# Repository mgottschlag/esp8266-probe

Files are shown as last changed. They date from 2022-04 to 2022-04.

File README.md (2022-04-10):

# esp8266-probe

This repository contains a PCB design for a WIFI JTAG probe using the ESP-12
ESP8266 module. The probe is designed to be compatible with
[blackmagic-espidf](https://github.com/walmis/blackmagic-espidf). The JTAG
signals (+UART) are connected as follows to ESP8266 GPIOs:

| JTAG Signal | GPIO |
| --- | ---- |
| TXD | 1 |
| RXD | 3 |
| TMS/SWDIO | 4 |
| TCK/SWCLK | 5 |
| SRST | 12 |
| TDI | 13 |
| TDO | 14 |

In addition, the 10-pin connector provides 5V and 3.3V supplies. The PCB is
provided with power via USB and 3.3V is provided by a cheap 1117 linear
regulator.

## License

The design is licensed under the [CERN Open Hardware Licence Version 2 - Permissive](cern-ohl_p_v2.txt).

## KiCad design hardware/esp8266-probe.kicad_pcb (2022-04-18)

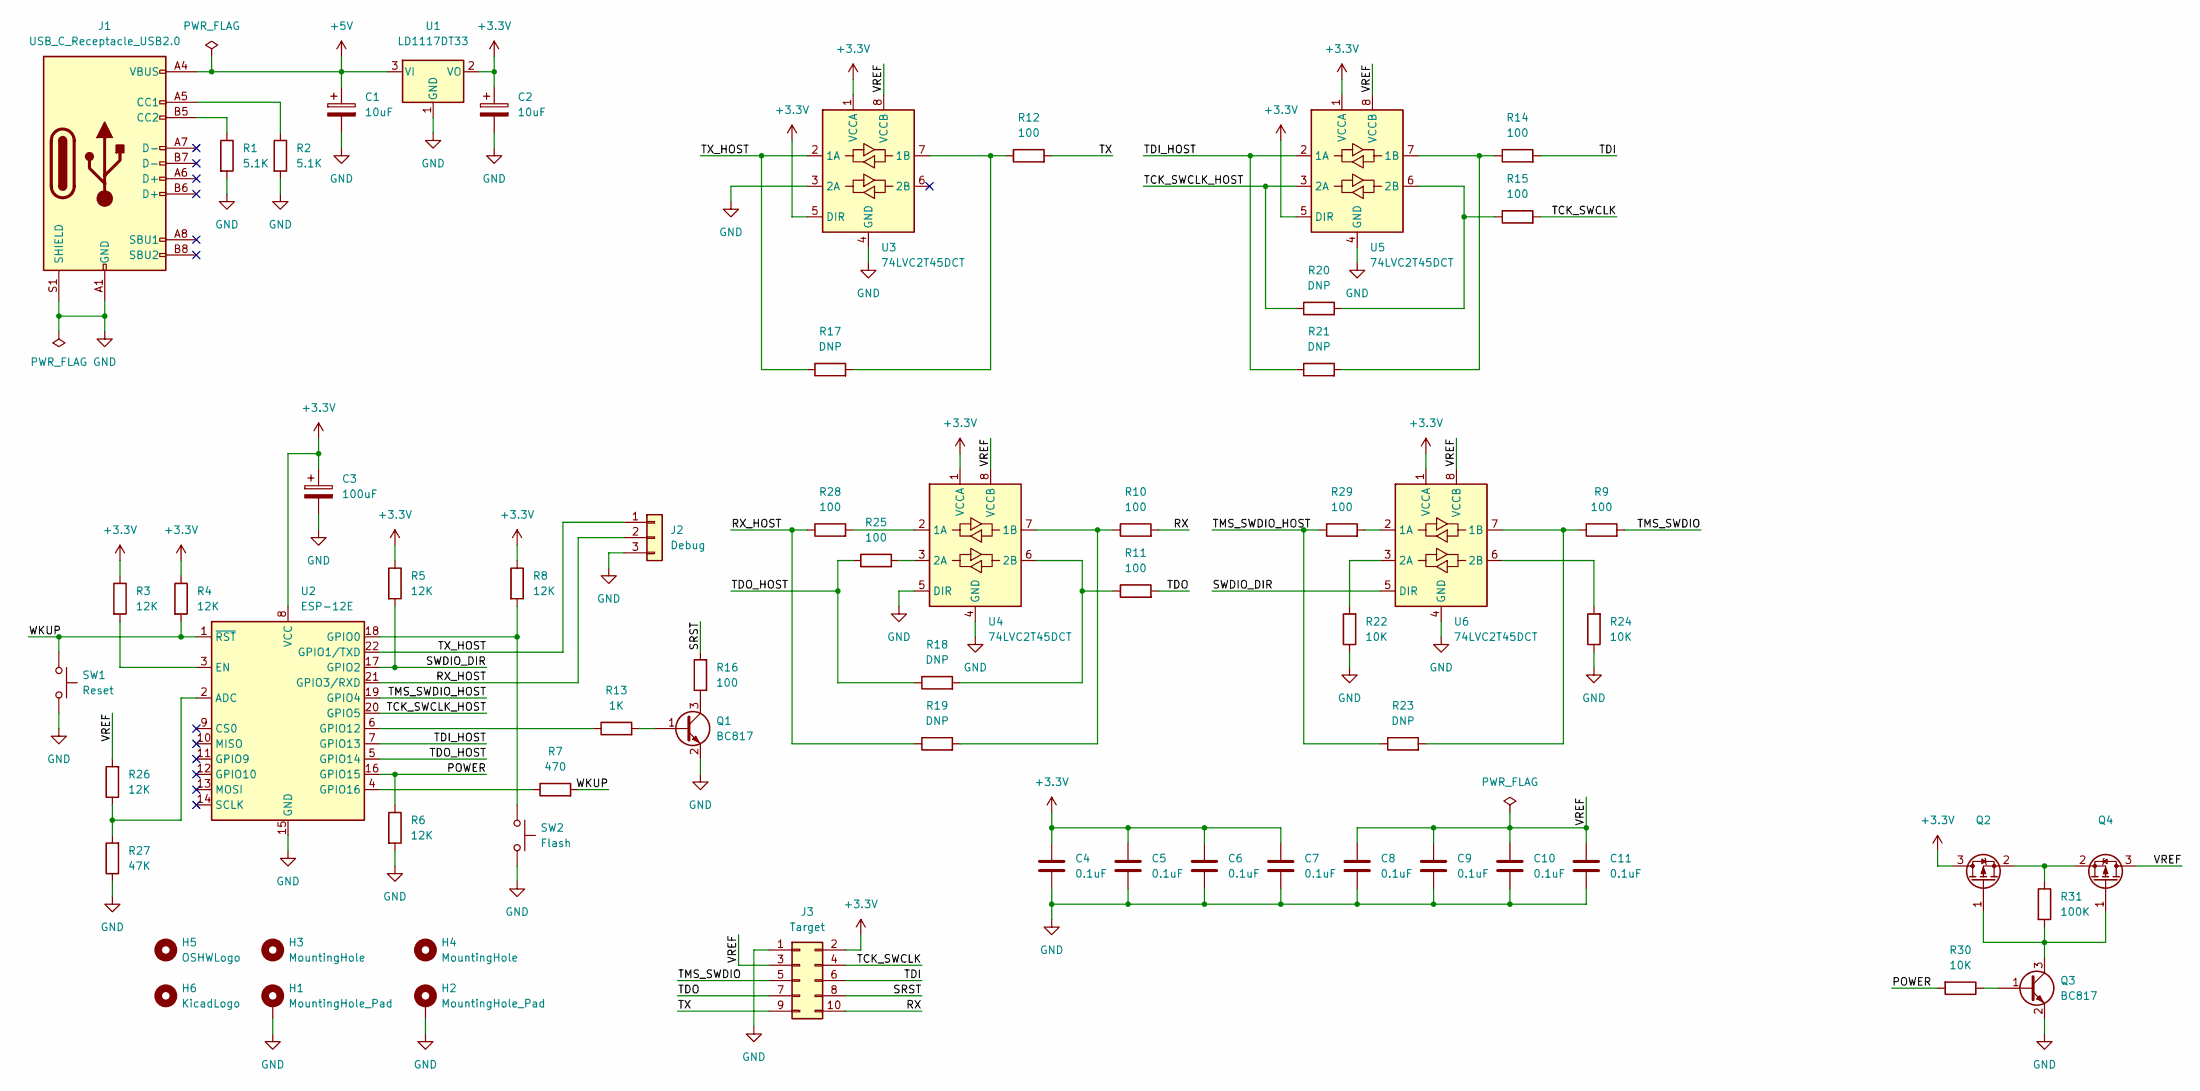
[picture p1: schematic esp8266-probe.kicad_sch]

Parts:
C1, C2: 10uF; CP_EIA-6032-20_AVX-F_Pad2.25x2.35mm_HandSolder
C3: 100uF; CP_Radial_D6.3mm_P2.50mm
C4, C5, C6, C7, C8, C9, C10, C11: 0.1uF; C_0603_1608Metric
H1, H2: MountingHole_Pad; MountingHole_3.2mm_M3_Pad
H3, H4: MountingHole; MountingHole_3.2mm_M3
H5: OSHWLogo; OSHW-Logo_5.7x6mm_SilkScreen
H6: KicadLogo; KiCad-Logo2_5mm_SilkScreen
J1: USB_C_Receptacle_USB2.0; USB_C_Receptacle_HRO_TYPE-C-31-M-12
J2: Debug; PinHeader_1x03_P2.54mm_Vertical
J3: Target; IDC-Header_2x05_P2.54mm_Vertical
Q1, Q3: BC817; SOT-23
Q2: (no value)
Q4: SOT-23
R1, R2: 5.1K; R_0603_1608Metric
R3, R4, R5, R6, R8, R26: 12K; R_0603_1608Metric
R7: 470; R_0603_1608Metric
R9, R10, R11, R12, R14, R15, R16, R25, R28, R29: 100; R_0603_1608Metric
R13: 1K; R_0603_1608Metric
R17, R18, R19, R20, R21, R23: DNP; R_0603_1608Metric
R22, R24, R30: 10K; R_0603_1608Metric
R27: 47K; R_0603_1608Metric
R31: 100K; R_0603_1608Metric
SW1: Reset; SW_SPST_PTS810
SW2: Flash; SW_SPST_PTS810
U1: LD1117DT33; TO-252-2
U2: ESP-12E
U3, U4, U5, U6: 74LVC2T45DCT; VSSOP-8_3.0x3.0mm_P0.65mm

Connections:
+3V3: C2.1, C3.1, C4.1, C5.1, C6.1, C7.1, J3.2, Q2.3 (D), R3.1, R4.1, R5.1, R8.1, U1.2 (VO), U2.8 (VCC), U3.1 (VCCA), U3.5 (DIR), U4.1 (VCCA), U5.1 (VCCA), U5.5 (DIR), U6.1 (VCCA)
+5V: C1.1, J1.A4 (VBUS), J1.A9 (VBUS), J1.B4 (VBUS), J1.B9 (VBUS), U1.3 (VI)
/POWER: R6.1, R30.2, U2.16 (GPIO15)
/RX: J3.10, R10.2
/RX_HOST: J2.2, R19.1, R28.1, U2.21 (GPIO3/RXD)
/SRST: J3.8, R16.2
/SWDIO_DIR: R5.2, U2.17 (GPIO2), U6.5 (DIR)
/TCK_SWCLK: J3.4, R15.2
/TCK_SWCLK_HOST: R20.1, U2.20 (GPIO5), U5.3 (2A)
/TDI: J3.6, R14.2
/TDI_HOST: R21.1, U2.7 (GPIO13), U5.2 (1A)
/TDO: J3.7, R11.2
/TDO_HOST: R18.1, R25.1, U2.5 (GPIO14)
/TMS_SWDIO: J3.5, R9.2
/TMS_SWDIO_HOST: R23.1, R29.1, U2.19 (GPIO4)
/TX: J3.9, R12.2
/TX_HOST: J2.1, R17.1, U2.22 (GPIO1/TXD), U3.2 (1A)
/VREF: C8.1, C9.1, C10.1, C11.1, J3.3, Q4.3 (D), R26.2, U3.8 (VCCB), U4.8 (VCCB), U5.8 (VCCB), U6.8 (VCCB)
/WKUP: R4.2, R7.2, SW1.1, U2.1 (~RST)
GND: C1.2, C2.2, C3.2, C4.2, C5.2, C6.2, C7.2, C8.2, C9.2, C10.2, C11.2, H1.1, H2.1, J1.A1 (GND), J1.A12 (GND), J1.B1 (GND), J1.B12 (GND), J1.S1 (SHIELD), J2.3, J3.1, Q1.2 (E), Q3.2 (E), R1.2, R2.2, R6.2, R22.1, R24.1, R27.1, SW1.2, SW2.2, U1.1 (GND), U2.15 (GND), U3.3 (2A), U3.4 (GND), U4.4 (GND), U4.5 (DIR), U5.4 (GND), U6.4 (GND)
unnamed: J1.A5 (CC1), R2.1
unnamed: J1.B5 (CC2), R1.1
unnamed: Q1.1 (B), R13.2
unnamed: Q1.3 (C), R16.1
unnamed: Q2.1 (G), Q3.3 (C), Q4.1 (G), R31.2
unnamed: Q2.2 (S), Q4.2 (S), R31.1
unnamed: Q3.1 (B), R30.1
unnamed: R3.2, U2.3 (EN)
unnamed: R7.1, U2.4 (GPIO16)
unnamed: R8.2, SW2.1, U2.18 (GPIO0)
unnamed: R10.1, R19.2, U4.7 (1B)
unnamed: R11.1, R18.2, U4.6 (2B)
unnamed: R12.1, R17.2, U3.7 (1B)
unnamed: R13.1, U2.6 (GPIO12)
unnamed: R14.1, R21.2, U5.7 (1B)
unnamed: R15.1, R20.2, U5.6 (2B)
unnamed: R22.2, U6.3 (2A)
unnamed: R9.1, R23.2, U6.7 (1B)
unnamed: R24.2, U6.6 (2B)
unnamed: R25.2, U4.3 (2A)
unnamed: R26.1, R27.2, U2.2 (ADC)
unnamed: R28.2, U4.2 (1A)
unnamed: R29.2, U6.2 (1A)

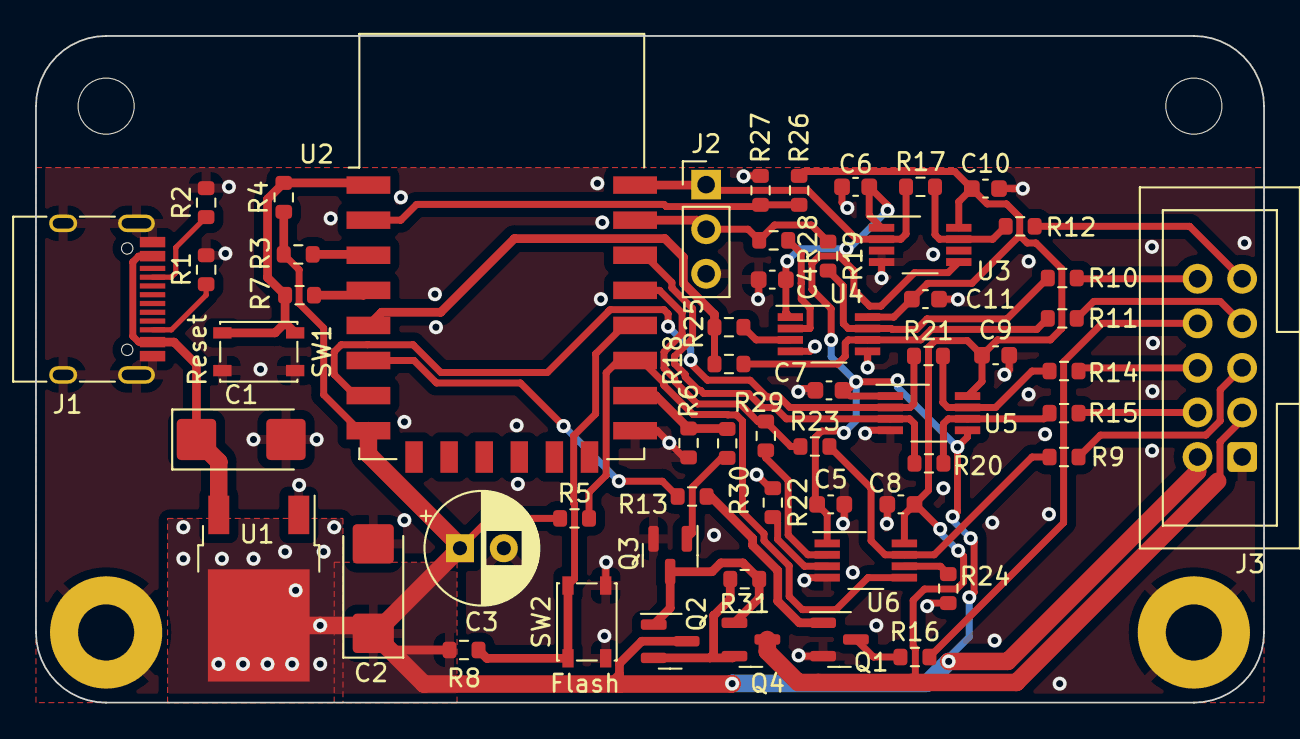
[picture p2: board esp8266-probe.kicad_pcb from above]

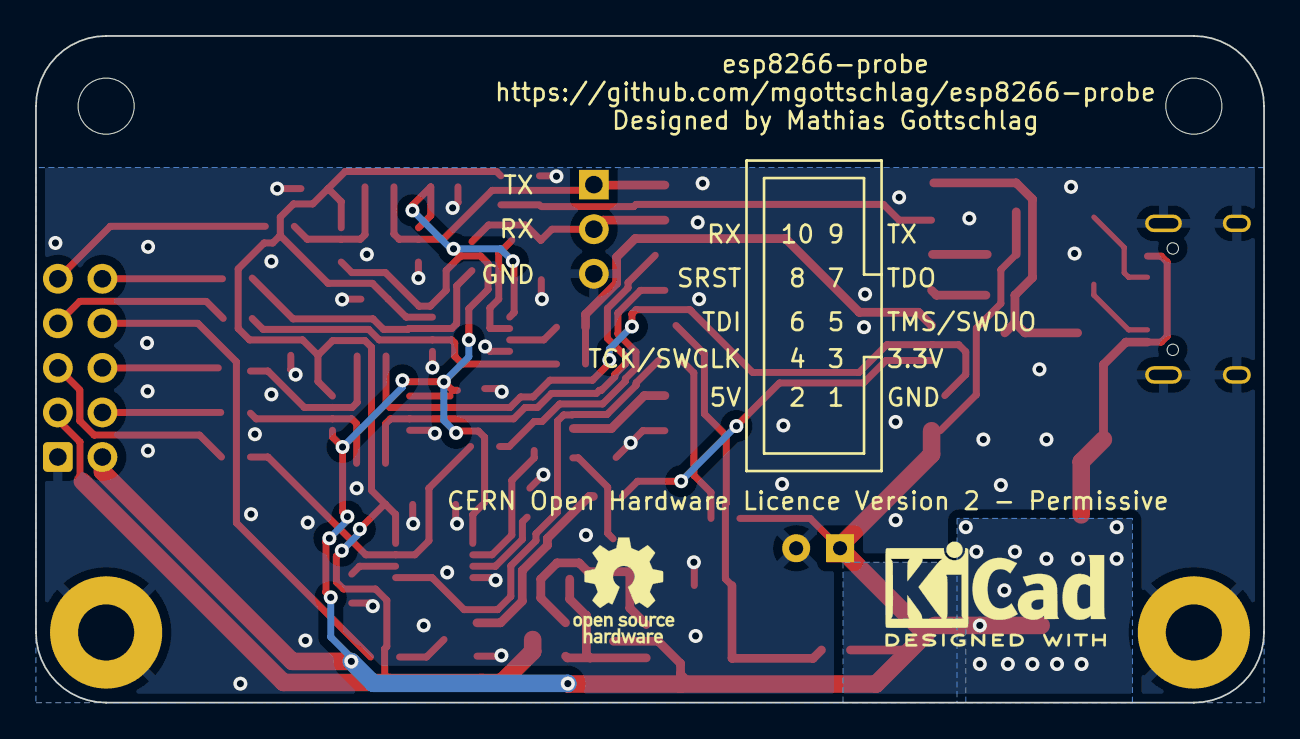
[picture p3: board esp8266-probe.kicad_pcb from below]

Board: 2 copper layers, 70.0 x 38.0 mm, 63 parts (2 on the bottom side), 43 nets.

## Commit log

2022-04-10 Initial import of the PCB.
    [esp8266-probe.kicad_pcb, esp8266-probe.kicad_sch]
2022-04-10 Improve thermal design around the linear regulator.
    [esp8266-probe.kicad_pcb]
2022-04-10 Add more ground vias.
    [esp8266-probe.kicad_pcb]
2022-04-10 Add DebugEdge git submodule (for the KiCAD symbol/footprint).
2022-04-18 Added level shifters and power to the PCB.
    [esp8266-probe.kicad_pcb, esp8266-probe.kicad_sch]
